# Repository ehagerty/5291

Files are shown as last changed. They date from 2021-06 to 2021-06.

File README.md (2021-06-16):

#  All original rights to manisteinn from Deskthority...

readme copied from https://github.com/qmk/qmk_firmware/tree/master/keyboards/converter/ibm_5291

# IBM 5291 keyboard converter

[IBM 5291](https://deskthority.net/wiki/IBM_Model_F#IBM_5291_Keyboard)

A converter for the eponymous keyboard.

Keyboard Maintainer: [Listofoptions](https://github.com/listofoptions)
Hardware Supported: IBM 5291, Teensy 2.0

Make example for this keyboard (after setting up your build environment):

    make converter/ibm_5291:default

See the [build environment setup](https://docs.qmk.fm/#/getting_started_build_tools) and the [make instructions](https://docs.qmk.fm/#/getting_started_make_guide) for more information. Brand new to QMK? Start with our [Complete Newbs Guide](https://docs.qmk.fm/#/newbs).

The pinout is as follows:

IBM−5291−Cable to Pinhead−14

| pin | description |
| --- | --- |
| 1 | GND |
| 2 | NC |
| 3 | GND |
| 4 | GN) |
| 5 | +5V |
| 6 | D0 |
| 7 | D1 |
| 8 | D2 |
| 9 | D3 |
| 10  | D4 |
| 11  | D5 |
| 12  | D6 |
| 13  | Strobe |
| 14  | Out |

The pins on this connector are organized
here

IBM−5291−2 Cable with DB15M connector

| pin | description |
| ----- | --- |
| 1,2,3 | GND |
| 4 | +5V |
| 5 | D0 |
| 6 | D1 |
| 7 | D2 |
| 8 | D3 |
| 9 | D4 |
| 10 | D5 |
| 11 | D6 |
| 12 | Strobe |
| 13 | Out |
| 14 | PE |
| 15 | NC |

The above connector is actually numbered so it should be easier to determine
where the needed connections are.

To connect to the teensy, the following are pins are needed (if you should choose not set your own):

- PB0 -> PB6 are connected to D0 -> D6
- +5V is connected to the corresponding teensy pin
- gnd is as well, only one of the gnd pins needs to be connected though.
- strobe is connected to pin PD1
- data is connected to PD0
- PE does not need to be connected to anything, but it could also be connected to gnd

sources:
http://www.retrocomputing.eu/documents/5291_MaintenanceLibrary.pdf

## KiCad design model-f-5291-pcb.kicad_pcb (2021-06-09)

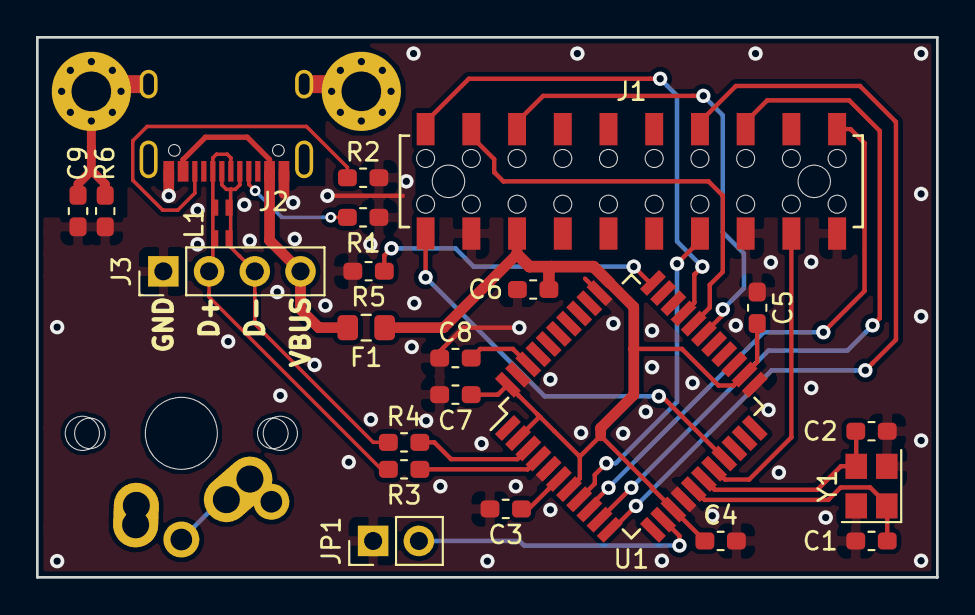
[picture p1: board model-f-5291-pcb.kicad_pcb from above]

Board: 2 copper layers, 50.0 x 30.0 mm, 26 parts (0 on the bottom side), 25 nets.

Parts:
C1, C2: 18p; C_0603_1608Metric_Pad1.05x0.95mm_HandSolder
C3: 1u; C_0603_1608Metric_Pad1.05x0.95mm_HandSolder
C4, C5, C6, C7, C8, C9: 0.1u; C_0603_1608Metric_Pad1.05x0.95mm_HandSolder
F1: Polyfuse; Fuse_0805_2012Metric_Pad1.15x1.40mm_HandSolder
J1: Keyboard; Harwin-M20-7811045
J2: USB_C_Receptacle; USB_TypeC_U31F-24SNA0201
J3: USB; PinHeader_1x04_P2.54mm_Vertical
JP1: Jumper_NO_Small; PinHeader_1x02_P2.54mm_Vertical
L1: DLW21SN900SQ2L; DLW21
MH1, MH2: MountingHole_Pad; MountingHole_2.2mm_M2_Pad_Via
R1, R2: 5.1K; R_0603_1608Metric_Pad1.05x0.95mm_HandSolder
R3, R4: 22; R_0603_1608Metric_Pad1.05x0.95mm_HandSolder
R5: 1K; R_0603_1608Metric_Pad1.05x0.95mm_HandSolder
R6: 330; R_0603_1608Metric_Pad1.05x0.95mm_HandSolder
SW1: SW_SPST; MX_Matias_KailhLP_NoSilk
U1: ATmega32U4-AU; TQFP-44_10x10mm_P0.8mm
Y1: Crystal_GND24; Crystal_SMD_3225-4Pin_3.2x2.5mm

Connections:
+5V: C4.1, C5.1, C6.1, C7.1, F1.1, J1.13, U1.2, U1.7, U1.14, U1.24, U1.34, U1.44
/CC1: J2.A5, R1.1
/CC2: J2.B5, R2.1
/Count1: J1.17, U1.8
/Count2: J1.1, U1.9
/Count4: J1.3, U1.10
/Count8: J1.4, U1.11
/Count16: J1.8, U1.28
/Count32: J1.9, U1.29
/Count64: J1.10, U1.30
/D+: J2.A6, J2.B6, J3.2, L1.1, L1.2, R3.1
/D-: J2.A7, J2.B7, J3.3, L1.3, L1.4, R4.1
/Key_Depressed: J1.11, U1.19
/Matrix_Strobe: J1.19, U1.18
/Shield: C9.1, J2.S1, MH1.1, MH2.1, R6.1
/VBUS_CON: F1.2, J2.A4, J2.B4, J3.4
/~RESET: JP1.2, U1.13
GND: C1.2, C2.2, C3.2, C4.2, C5.2, C6.2, C7.2, C8.2, C9.2, J1.12, J1.18, J1.20, J2.A1, J2.B1, J3.1, JP1.1, R1.2, R2.2, R5.1, R6.2, U1.5, U1.15, U1.23, U1.35, U1.43, Y1.2, Y1.4
unnamed: C1.1, U1.16, Y1.1
unnamed: C2.1, U1.17, Y1.3
unnamed: C3.1, U1.6
unnamed: C8.1, U1.42
unnamed: R3.2, U1.4
unnamed: R4.2, U1.3
unnamed: R5.2, U1.33
